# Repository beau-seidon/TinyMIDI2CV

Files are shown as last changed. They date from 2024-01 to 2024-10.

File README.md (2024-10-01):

# TinyMIDI2CV
ATTiny85 circuit which takes TTL-MIDI input and outputs a 1V/Octave CV and a Gate CV signal, as well as an attenuatable 0-5V CV signal (modes configurable via MIDI program change or SysEx messages).

This circuit can be embedded in other projects, or built standalone. I built mine in the form of a eurorack module.

<p float="left">
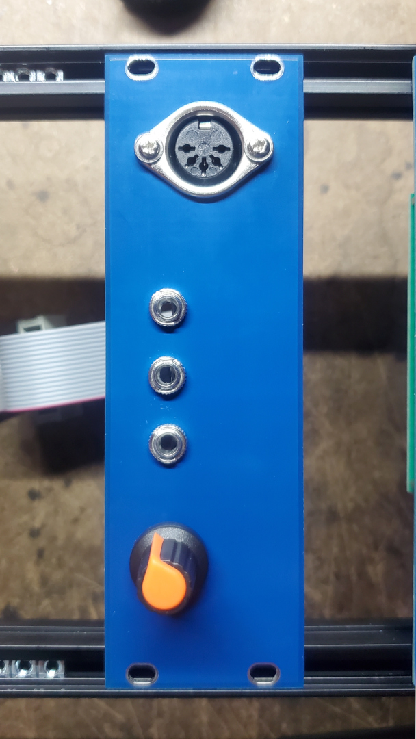
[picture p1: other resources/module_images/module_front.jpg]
  
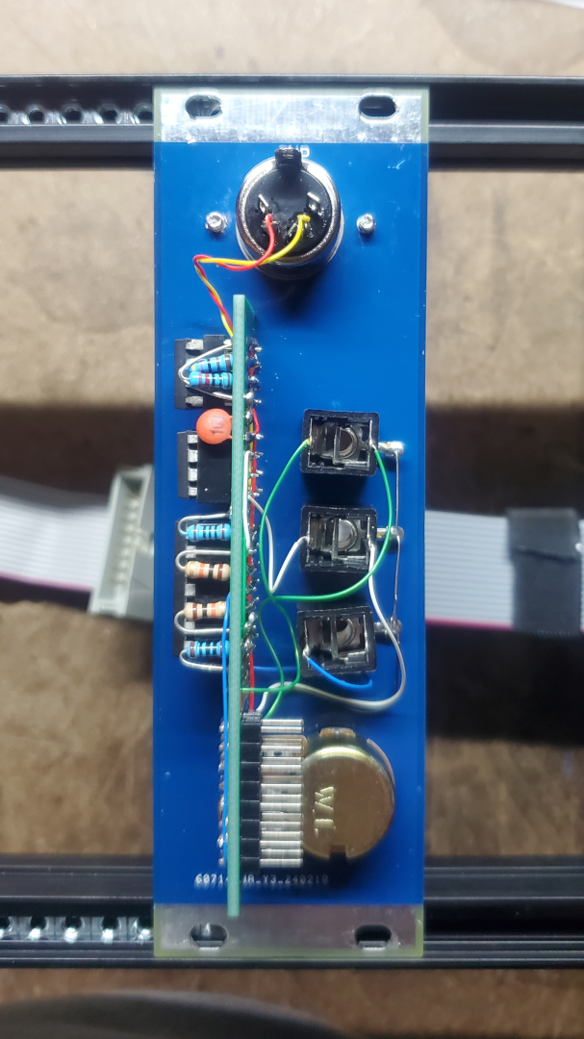
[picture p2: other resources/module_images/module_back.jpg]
  
</p>

### To-Do:
- EEPROM write cv2 mode configurations etc. after changes
- Update hardware drawings
- Design compact PCB
- (include ISP pins?)

### Changes
- Added SysEx listener for configuring CV2, MIDI Channel, retrig mode, CC filter. Added Paraphonic Note mode for CV2. Added more options for retrigger. Updated project name. Created SysEx reference document.

- Further improvements to note buffer / gate behavior. Added MIDI CC legato (68) handler to enable/disable gate retrigger. MIDI filter default channel is now 1. More function compartmentalization for readability. Added alternative methods to control CV2 output, selectable via MIDI Program Change. More CV2 functions to come soon.

- Original code (in goMIDI2CV.ino file) has been moved to jo_original branch to simplify the repo

- MIDI channel filtering is fixed in latest commmit, and default is channel 16. Can change channel or enable Omni in source and recompile if desired.

- Updated the [schematic](./hardware/TinyMIDI2CV.pdf), which should now be suitable for creating a small Eurorack module.  It's only my second module I have built, so feel free to improve it.

-  Overhauled most of the code styling, and fixed the Gate CV behavior. Now Gate remains High as long as any note is still held.  Also, retrigger functionality was added. Gate pin goes Low very briefly, then quickly back to High, any time a new note is played while other notes are held.

- A note buffer array now remembers active notes in the order they were played.  Note CV output returns to previous note value if it is still held when the most recent note is released.  Note CV output does not change when the final note is released, but the Gate CV goes Low.

- Fixed the way the code responds to MIDI messages and handles running status. Pitch bend is now functional.  Broke out handlers for different types of messages like note on/off, bend, gate, etc. into their own defined functions.

- After much fiddling with different summing circuits and testing with my synth, I determined that a seperate output jack for pitchbend is more convenient for me than coupling it to the Note CV.  This is shown in the new schematic. If you find a nicer way to do it, let me know.

- The barest bones for handling MIDI CC and velocity, and sending CV Trigger output are in place as well. Further development on those will be started soon in another branch.

### Programming
I program my ATTiny85 using an Arudino Uno as an ISP programmer, following instructions shown here and other places:
[https://circuitdigest.com/microcontroller-projects/programming-attiny85-microcontroller-ic-using-arduino]

You can paste the contents of [main.cpp](./software/src/main.cpp) into the ArduinoIDE and directly follow the instructions on that site to load it to your chip.
Or if you prefer VSCode with PlatformIO, you can use the settings in this repo's [platform.ini](./software/platform.ini) file to program the ATTiny85 using an Uno as an ISP. You may need to change some of those parameters if you use a different programmer.

Notice, that site doesn't explain how to set the fuse bits before flashing the firmware, but I included a [text file](./software/attiny85%20fuse%20settings.txt) with brief instructions on this, and the relevant terminal commands (for Windows).

## DIY Good Ol’ MIDI to CV
This project began as a reworked and expanded version of the DIY Good Ol’ MIDI to CV project by Jan Ostman.
Original project: [https://www.hackster.io/janost/diy-good-ol-midi-to-cv-d0e2bf]

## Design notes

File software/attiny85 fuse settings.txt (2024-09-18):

Assuming ArduinoIDE is installed, the following command will set the fuse bits correctly for TinyMIDI2CV, while using an Arudino Uno as an ISP programmer for the ATTiny85:

"C:\Program Files (x86)\Arduino\hardware\tools\avr/bin/avrdude" -C "C:\Program Files (x86)\Arduino\hardware\tools\avr/etc/avrdude.conf" -v -p attiny85 -c stk500v1 -P COM4 -b 19200 -e -U lfuse:w:0xe1:m -U hfuse:w:0xdd:m -U efuse:w:0xfe:m

You may need to change the COM port number to match your device. The correct number may be found in the Windows Device Manager, or in the Tools > Port menu in ArduinoIDE. 

If using VSCode & PlatformIO, make sure your programmer is configured correctly in platformio.ini and add the following lines:

; ATTiny85 16Mhz
board_fuses.lfuse = 0xE1
board_fuses.hfuse = 0xDD
board_fuses.efuse = 0xFE

Then in the menu bar up top, click: 
	Terminal > Run Task

and run the task: 
	PlatformIO: Set Fuses

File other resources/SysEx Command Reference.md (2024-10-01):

## SET MIDI CHANNEL
#### COMMAND = 01, DATA = [00-10]

- F0 7D 42 01 00 F7 = Channel 01
- F0 7D 42 01 01 F7 = Channel 02
- F0 7D 42 01 02 F7 = Channel 03
- . . .
- F0 7D 42 01 0E F7 = Channel 15
- F0 7D 42 01 0F F7 = Channel 16
- F0 7D 42 01 10 F7 = Omni ON (^others set Omni to OFF)

## SET MIDI CC FILTER
#### COMMAND = 02, DATA = [00-FF]

- F0 7D 42 02 00 F7 = CC# 1
- F0 7D 42 02 01 F7 = CC# 2
- F0 7D 42 02 02 F7 = CC# 3
- . . .
- F0 7D 42 02 FE F7 = CC# 127
- F0 7D 42 02 FF F7 = CC# 128

## SET CV2 SOURCE
#### COMMAND = 03, DATA = [00-FF]

- F0 7D 42 03 00 F7 - Pitch Bend
- F0 7D 42 03 01 F7 - Mod Wheel
- F0 7D 42 03 02 F7 - CC
- F0 7D 42 03 03 F7 - Velocity
- F0 7D 42 03 04 F7 - Note
- F0 7D 42 03 05 F7 - Note (Inverted Keyboard)
- F0 7D 42 03 06 F7 - Gate
- F0 7D 42 03 07 F7 - Gate (Inverted)
- F0 7D 42 03 08 F7 - Paraphonic Notes
- F0 7D 42 03 09 F7 - Increment Paraphonic Mode
- F0 7D 42 03 0A F7 - Increment Retrigger Mode
- F0 7D 42 03 0B F7 - Unused...
- F0 7D 42 03 0C F7 - Trigger (Not implemented yet)
- F0 7D 42 03 0D F7 - Envelope (Not implemented yet)
- F0 7D 42 03 0E F7 - LFO (Not implemented yet)
- F0 7D 42 03 0F F7 - Sync (Not implemented yet)

## SET PARAPHONIC MODE
#### COMMAND = 04, DATA = [00-08]

- F0 7D 42 04 00 F7 - Recent (CV1 = new)
- F0 7D 42 04 01 F7 - Recent Inverted (CV2 = new)
- F0 7D 42 04 02 F7 - Recent Lo (CV2 = low)
- F0 7D 42 04 03 F7 - Recent Hi (CV2 = high)
- F0 7D 42 04 04 F7 - Outer (CV1 = high)
- F0 7D 42 04 05 F7 - Outer Inverted (CV1 = low)
- F0 7D 42 04 06 F7 - Low (CV2 = low)
- F0 7D 42 04 07 F7 - Hi (CV2 = high)
- F0 7D 42 04 08 F7 - Pedal (CV2 = first note in buffer)

## SET RETRIGGER MODE
#### COMMAND = 05, DATA = [00-02]

- F0 7D 42 05 00 F7 - Off
- F0 7D 42 05 01 F7 - New
- F0 7D 42 05 02 F7 - Always

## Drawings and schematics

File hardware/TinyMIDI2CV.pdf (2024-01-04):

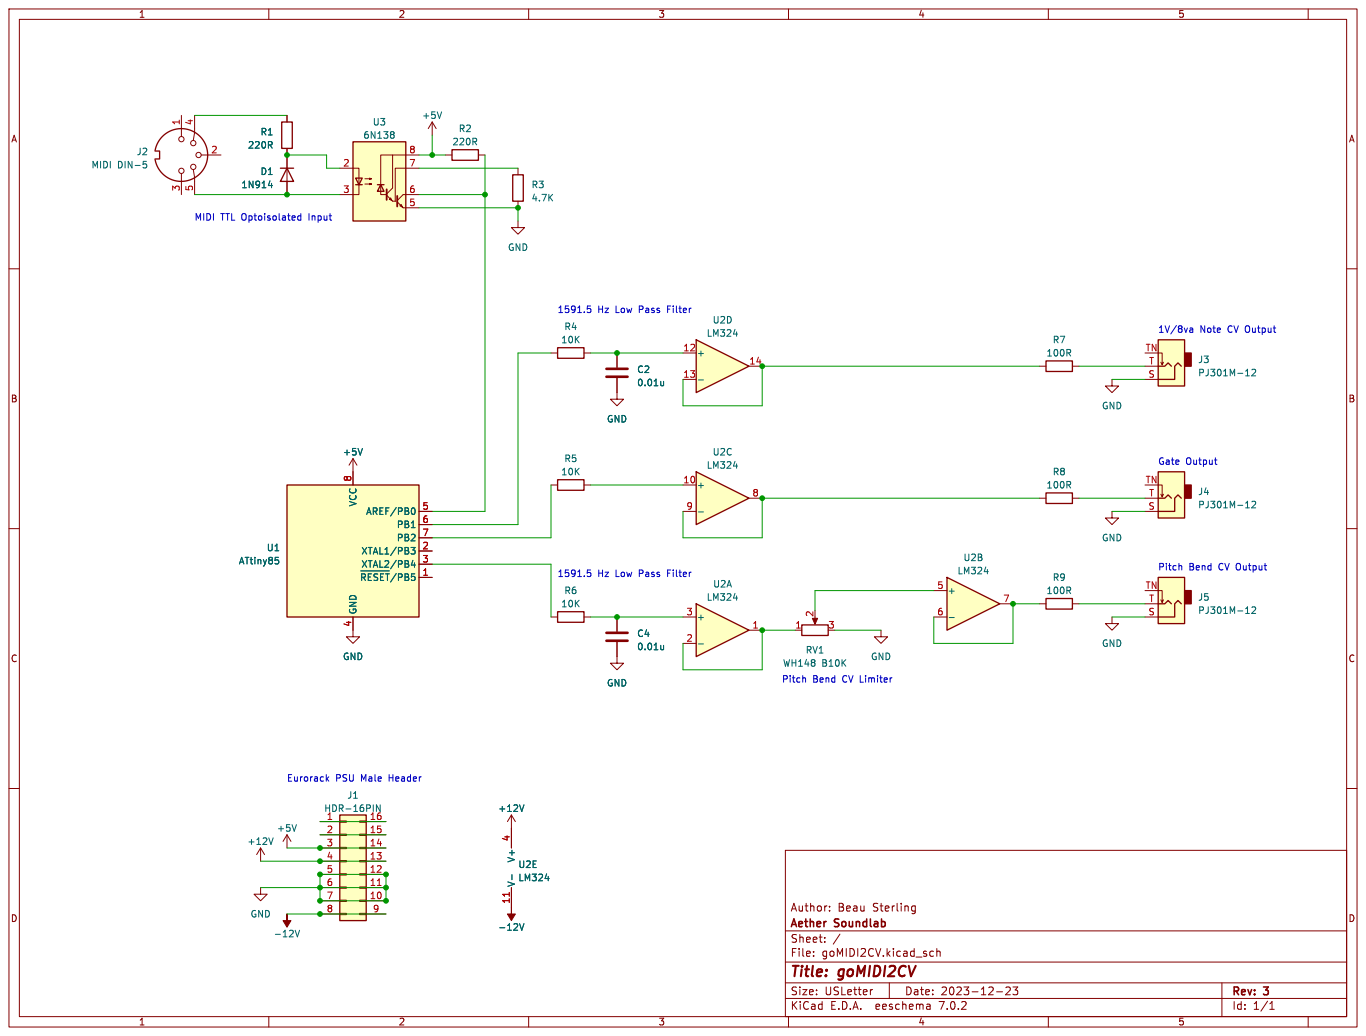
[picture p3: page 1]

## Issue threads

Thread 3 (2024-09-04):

Playing notes while pitch-bending sometimes causes CV2 source to change

beau-seidon, 2024-09-04:
Playing notes while wailing on the pitch-bend wheel seems to be interpreted as a garbage program change message, sending the CV2_MODE switch to the default case. Specifically, the note RELEASE is what seems to break it. Needs further diagnosis.

beau-seidon, 2024-09-18:
fixed by 5b201bba919181eaff70af9d0bc46905dca8b65c

beau-seidon, 2024-09-18:
fixed by 5b201bba919181eaff70af9d0bc46905dca8b65c

Closed 2024-09-18.

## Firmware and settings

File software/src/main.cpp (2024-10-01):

/*
    TinyMIDI2CV

    Copyright 2023-2024 Beau Sterling (Aether Soundlab)

    Hardware config is based on DIY Good Ol’ MIDI to CV by Jan Ostman:
        (*) All in the spirit of open-source and open-hardware
        Janost 2019 Sweden
        The goMIDI2CV interface
        http://blog.dspsynth.eu/diy-good-ol-midi-to-cv/
        Copyright 2019 DSP Synthesizers Sweden.


    This file is part of TinyMIDI2CV.

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
    You should have received a copy of the GNU General Public License along with
    TinyMIDI2CV. If not, see <https://www.gnu.org/licenses/>.
*/


// Set Fuses to E1 DD FE for PLLCLK 16MHz


#include <Arduino.h>
// #include <avr/io.h>
// #include <avr/pgmspace.h>
#include "global.h"
#include "midi.h"
#include "gate.h"
#include "cv2.h"


void setup()
{
    // Enable 64 MHz PLL and use as source for Timer1
    PLLCSR = 1 << PCKE | 1 << PLLE;

    // Setup the USI
    USICR = 0;                                      // Disable USI.
    GIFR = 1 << PCIF;                               // Clear pin change interrupt flag.
    GIMSK |= 1 << PCIE;                             // Enable pin change interrupts
    PCMSK |= 1 << PCINT0;                           // Enable pin change on pin 0

    // Set up Timer/Counter1 for PWM output
    TIMSK = 0;                                      // Timer interrupts OFF
    TCCR1 = 1 << PWM1A | 2 << COM1A0 | 1 << CS10;   // PWM A, clear on match, 1:1 prescale
    OCR1A = 0;                                      // Set initial Pitch to C2
    OCR1B = 127;                                    // Set initial CV to center (pitchbend center)
    OCR1C = 239;                                    // Set count to semi tones

    GTCCR = 0;
    GTCCR = 1 << PWM1B | 2 << COM1B0;               // PWM B, clear on match

    // Setup GPIO
    pinMode(USI_PIN, INPUT);                        // Enable USI input pin
    pinMode(NOTE_CV_PIN, OUTPUT);                   // Enable PWM output pin
    pinMode(GATE_CV_PIN, OUTPUT);                   // Enable Gate output pin
    pinMode(MISC_CV_PIN, OUTPUT);                   // Enable CV2 PWM output pin

    sendGate(GATE_CLOSED);                          // Set initial Gate to LOW;
    setCV2Mode(CV2_PITCH_BEND);                     // Set initial CV2 source to Pitchbend
}


void loop()
{
    // do nothing, everything happens via interrupts
}

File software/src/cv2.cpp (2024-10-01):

/*
    TinyMIDI2CV

    Copyright 2023-2024 Beau Sterling (Aether Soundlab)

    Hardware config is based on DIY Good Ol’ MIDI to CV by Jan Ostman:
        (*) All in the spirit of open-source and open-hardware
        Janost 2019 Sweden
        The goMIDI2CV interface
        http://blog.dspsynth.eu/diy-good-ol-midi-to-cv/
        Copyright 2019 DSP Synthesizers Sweden.


    This file is part of TinyMIDI2CV.

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
    You should have received a copy of the GNU General Public License along with
    TinyMIDI2CV. If not, see <https://www.gnu.org/licenses/>.
*/


#include "cv2.h"
#include "midi.h"
#include "paraphonic.h"
#include "gate.h"


volatile CV2_MODE cv2 = CV2_MODWHEEL;


void setCV2Mode(uint8_t mode)
{
        switch((int)mode) {

            case CV2_MODE::CV2_PITCH_BEND:
                cv2 = CV2_PITCH_BEND;
                break;

            case CV2_MODE::CV2_MODWHEEL:
                cv2 = CV2_CC;
                setMIDICCFilter(MODWHEEL_CC);
                break;

            case CV2_MODE::CV2_CC:
                cv2 = CV2_CC;
                setMIDICCFilter(DEFAULT_CC);
                break;

            case CV2_MODE::CV2_VELOCITY:
                cv2 = CV2_VELOCITY;
                break;

            case CV2_MODE::CV2_NOTE:
                cv2 = CV2_NOTE;
                break;

            case CV2_MODE::CV2_NOTE_INV:
                cv2 = CV2_NOTE_INV;
                break;

            case CV2_MODE::CV2_GATE:
                cv2 = CV2_GATE;
                break;

            case CV2_MODE::CV2_GATE_INV:
                cv2 = CV2_GATE_INV;
                break;

            case CV2_MODE::CV2_PARAPHONIC:
                cv2 = CV2_PARAPHONIC;
                break;

            case CV2_MODE::CV2_PARA_SET:
                setParaphonicModePC();
                break;

            case CV2_MODE::CV2_RETRIG_SET:
                setRetrigModePC();
                break;

            case CV2_MODE::CV2_UNUSED:
                break;

            case CV2_MODE::CV2_TRIG:
                // cv2 = CV2_TRIG;
                break;

            case CV2_MODE::CV2_ENVELOPE:
                // cv2 = CV2_ENVELOPE;
                break;

            case CV2_MODE::CV2_LFO:
                // cv2 = CV2_LFO;
                break;

            case CV2_MODE::CV2_SYNC:
                // cv2 = CV2_SYNC;
                break;

            default:  // CV2_MODE::CV2_MODWHEEL
                cv2 = CV2_CC;
                setMIDICCFilter(MODWHEEL_CC);
                break;
        }
}


void sendNoteCV2(uint8_t note)
{
    OCR1B = note << 2;
}


void sendNoteCV2Inv(uint8_t note)
{
    OCR1B = OCR1C - (note << 2);
}


void sendGateCV2(uint8_t gate)
{
    if (cv2 == CV2_GATE) {
        if (gate) OCR1B = 255;
        else OCR1B = 0;
        return;
    }

    if (cv2 == CV2_GATE_INV) {
        if (gate) OCR1B = 0;
        else OCR1B = 255;
        return;
    }
}


void handleVelocity(uint8_t vel)
{
    if (cv2 == CV2_VELOCITY) OCR1B = vel << 1;
}


void handleControlChange(uint8_t cc_num, uint8_t cc_value)
{
    if (cv2 == CV2_CC && cc_num == MIDI_CC_FILTER) OCR1B = cc_value << 1;
}


void handlePitchBend(uint8_t data1, uint8_t data2)
{
    if (cv2 == CV2_PITCH_BEND) {
        // unsigned int bend;
        // bend = (unsigned int)data2;  // MSB
        // bend <<= 7;
        // bend |= (unsigned int)data1;  // LSB
        // uint8_t bend_CV = map(bend, BEND_MIN, BEND_MAX, 0, 255);

        uint8_t bend_CV = data2 << 1;  // MSB-only behaves better than map

        OCR1B = bend_CV;
    }
}


void handleProgramChange(uint8_t channel, uint8_t program)
{
    // setCV2Mode(program);
    if (program > 0 && program < PARAPHONIC_MODE_MAX) setParaphonicMode(program);
}

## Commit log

2023-12-12 Update main.cpp
    added midi channel filter and omni
2023-12-18 bug fixes in main.cpp
    removed bitand checking for voice category status (eg. midi_status & 0x90) because it made the pitch CV respond strangely to velocity.
    this broke the midi channel filter so it only responds to CH1 now, but note CV, gate, and pitch bend function again.
    will experiment with bitand and channel filtering again later
    [main.cpp]
2023-12-22 Update main.cpp
    changed pitch bend behavior, now with the intent of using it as a separate CV output.
    also added re-trigger functionality to the gate output. handleNoteOn() now turns off the gate for 32 microseconds, and sendGate turns it back on. this behavior can be disabled by setting the RETRIGGER constant to false. (there may be a better method than using delayMicroseconds, but i haven't noticed any bad behavior or missed MIDI.)
    [main.cpp]
2023-12-24 updated schematic
    [goMIDI2CV.kicad_sch]
2023-12-24 Update attiny85 fuse settings.txt
    added instructions for setting fuse bits using VSCode & PlatformIO
2023-12-24 Update platformio.ini
    added fuse settings for ATTiny85
2023-12-24 Update README.md
    added notes about programming and settings fuse bits
2023-12-24 Rename hardware/goMIDI2CV/goMIDI2CV.kicad_sch to hardware/goMIDI2CV.kicad_sch
    changed directory structure
    [goMIDI2CV.kicad_sch]
2023-12-24 Update README.md
    re-linked schematic
2024-01-04 replace files via upload
    fixed labels on gate and note cv outputs
    [goMIDI2CV.kicad_sch]
2024-01-06 Update main.cpp
    cleaned up code for readability and extensibility. fixed midi channel filtering, and pitch bend. added potential for midi CC and/or velocity handling, and trigger CV output. tested build with circuit shown in latest schematic.
    [main.cpp]
2024-01-06 Update README.md
    comments about code and schematic updates
2024-09-04 MIDI PC selectable CV2 and other features / fixes
    [main.cpp]
2024-09-18 Update and rename goMIDI2CV.kicad_sch to TinyMIDI2CV.kicad_sch
    [TinyMIDI2CV.kicad_sch]
2024-10-01 fixed sysex, updated cv2 modes etc
    [cv2.cpp, cvnote.cpp, gate.cpp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]

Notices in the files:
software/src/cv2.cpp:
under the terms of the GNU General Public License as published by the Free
